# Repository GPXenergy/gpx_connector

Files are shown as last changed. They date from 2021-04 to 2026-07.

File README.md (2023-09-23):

# GPX Connector

The GPX-Connector is part of the GPX system to connect a smart meter to the GPX 
multi-user system. It runs on an ESP32, which connects to the smart meter 
through a RJ11 cable and sends the data over wifi to the GPX API. 

## Latest firmware

Check out the firmware directory for the latest firmware, separated by hardware 
version. You will find the firmware for your specific hardware in its own directory:

* gpx_connector_v1 (current prototype)
  * Latest firmware: gpx_connector_1.0.9.bin
* ...

## Local development setup

The project runs on [PlatformIO](https://platformio.org/), an open source 
framework and IDE for embedded development. 

This project has 2 platformio environments:
* __GPXConnector__ (default) - The final device / prototypes to run the system
* __wrover__ - The ESP-WROVER-kit device, used for debugging

Some platformio commands:
* `pio run`
  * Compile the program on default environment (GPXConnector)
* `pio run -t upload -e GPXConnector`
  * Compile and upload the program for specific environment
* `pio test -e wrover`
  * Run all the unit tests on the wrover environment

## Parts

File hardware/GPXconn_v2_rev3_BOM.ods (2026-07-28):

Reference | Qty | DNP | Mfr. No | alternative | Manufacturer | Value | Tolerance | Voltage rating | Dielectric | Footprint | Datasheet
C1 | 1 |  | DGH504Q5R5 |  | Cornell Dubilier | 0.5F | 30%/-10% | 5.5V |  | custom:CP_Radial_L17_W8.5_P12 | https://www.cde.com/resources/catalogs/DGH.pdf
C2,C3 | 2 |  | capacitor 0805 |  |  | 22µ | 20% | 10V | X5R | Capacitor_SMD:C_0805_2012Metric | ~
C4 | 1 |  | capacitor 0603 |  |  | 33p | 10% | 10V | C0G(NP0) | Capacitor_SMD:C_0603_1608Metric | ~
C5,C7,C11 | 3 |  | capacitor 0603 |  |  | 100n | 10% | 10V | X5R | Capacitor_SMD:C_0603_1608Metric | ~
C6,C9 | 2 |  | capacitor 0603 |  |  | 10µ | 20% | 10V | X5R | Capacitor_SMD:C_0603_1608Metric | ~
C8 | 1 |  | capacitor 0603 |  |  | 1µ | 20% | 10V | X5R | Capacitor_SMD:C_0603_1608Metric | ~
C10,J0 | 2 | DNP | DNP |  |  | DNP |  |  |  | Capacitor_SMD:C_0603_1608Metric,Resistor_SMD:R_0603_1608Metric | ~
CONN1 | 1 |  | MTJ-665X1 |  | Adam Tech | RJ11 |  |  |  | custom:AMPHENOL_54601-906WPLF
CONN2 | 1 |  | SJ2-35813B-SMT-TR |  | Same Sky | JACK-3.5MM-3P-SW |  |  |  | custom:CUI_SJ2-35813B-SMT-TR | ~
CONN3 | 1 | DNP | DNP |  |  | PINHD_R_1X62.54MM |  |  |  | Connector_PinHeader_2.54mm:PinHeader_1x06_P2.54mm_Vertical | ~
D1 | 1 |  | BAT60JFILM |  | STMicroelectronics |  |  |  |  | Diode_SMD:D_SOD-323 | https://www.st.com/resource/en/datasheet/bat60.pdf
D3 | 1 |  | NSR0340HT1G |  | onsemi |  |  |  |  | Diode_SMD:D_SOD-323 | https://www.onsemi.com/download/data-sheet/pdf/nsr0340h-d.pdf
F1 | 1 |  | 0686F0500-01 |  | Bel Fuse | Fuse 0603 |  |  |  | Fuse:Fuse_0603_1608Metric | ~
L1 | 1 |  | CVH252009-2R2M |  | Bourns | 2.2µH | 20% |  |  | Inductor_SMD:L_1008_2520Metric | ~
LED1 | 1 |  | 150505M173300 |  | Wurth Elektronik | LED-RGB-NOCMN |  |  |  | custom:LED_5050_3535_combined | https://downloads.cree-led.com/files/ds/h/HB-CLX6F-FKC.pdf
N2 | 1 |  | 51513530625F |  | Dialight | Light pipe |  |  |  | custom:lightpipe_panelmount | ~
Q1 | 1 |  | MMBT3904VL |  | Nexperia | BJT-NPN-SOT23 |  |  |  | custom:SOT23 | https://www.onsemi.com/pdf/datasheet/pzt3904-d.pdf
Q2 | 1 |  | DMP3099L-7 |  | Diodes Incorporated | MOSFET-PSOT23 |  |  |  | custom:SOT23 | https://www.diodes.com/assets/Datasheets/DMP3099L.pdf
Q3 | 1 |  | T2N7002AK |  | Toshiba | 2N7002H |  |  |  | custom:SOT23 | https://toshiba.semicon-storage.com/info/docget.jsp?did=29712&prodName=T2N7002AK
FB1,R17 | 2 |  | resistor 0603 |  |  | 0R |  |  |  | Resistor_SMD:R_0603_1608Metric | ~
R1 | 1 |  | resistor 0603 |  |  | 1k2 1% | 1% |  |  | Resistor_SMD:R_0603_1608Metric | ~
R2 | 1 |  | resistor 0603 |  |  | 51k 1% | 1% |  |  | Resistor_SMD:R_0603_1608Metric | ~
R3,R18,R19,R22,R27 | 5 |  | resistor 0603 |  |  | 10k | 1% |  |  | Resistor_SMD:R_0603_1608Metric | ~
R4 | 1 |  | resistor 0603 |  |  | 15k | 1% |  |  | Resistor_SMD:R_0603_1608Metric | ~
R5 | 1 |  | resistor 0603 |  |  | 47k | 1% |  |  | Resistor_SMD:R_0603_1608Metric | ~
R6,R20,R24,R25 | 4 |  | resistor 0603 |  |  | 5k1 | 1% |  |  | Resistor_SMD:R_0603_1608Metric | ~
R7 | 1 |  | resistor 0603 |  |  | 51 | 1% |  |  | Resistor_SMD:R_0603_1608Metric | ~
R8 | 1 |  | resistor 0603 |  |  | 115k 1% | 1% |  |  | Resistor_SMD:R_0603_1608Metric | ~
R9 | 1 |  | resistor 0603 |  |  | 25.5k 1% | 1% |  |  | Resistor_SMD:R_0603_1608Metric | ~
R10 | 1 |  | resistor 0603 |  |  | 47k 1% | 1% |  |  | Resistor_SMD:R_0603_1608Metric | ~
R11 | 1 |  | resistor 0603 |  |  | 18k 1% | 1% |  |  | Resistor_SMD:R_0603_1608Metric | ~
R12 | 1 |  | resistor 0603 |  |  | 750 | 1% |  |  | Resistor_SMD:R_0603_1608Metric | ~
R13 | 1 |  | resistor 0603 |  |  | 510 | 1% |  |  | Resistor_SMD:R_0603_1608Metric | ~
R14 | 1 |  | resistor 0603 |  |  | 1k6 | 1% |  |  | Resistor_SMD:R_0603_1608Metric | ~
R15,R16 | 2 |  | resistor 0603 |  |  | 100k | 1% |  |  | Resistor_SMD:R_0603_1608Metric | ~
R21,R23,R26 | 3 |  | resistor 0603 |  |  | 100 | 1% |  |  | Resistor_SMD:R_0603_1608Metric | ~
RS0 | 1 |  | RL0816S-R30-F |  | Susumu | 300mOhm 1% | 1% |  |  | Resistor_SMD:R_0603_1608Metric | ~
SW1 | 1 |  | 1MS1T2B4M6RE |  | MULTICOMP PRO | SW_SPDT |  |  |  | custom:SW-1MS1-T2-B4-M6 | http://www.farnell.com/datasheets/3968494.pdf
U1 | 1 |  | ESP32-WROOM-32E-H4 | ESP32-WROOM-32E-N16 | Espressif Systems | ESP-WROOM-3232D |  |  |  | RF_Module:ESP32-WROOM-32D | https://www.espressif.com/sites/default/files/documentation/esp32-wroom-32e_esp32-wroom-32ue_datasheet_en.pdf
U2 | 1 |  | TPS563252DRLR |  | Texas Instruments | TPS563252 |  |  |  | Package_TO_SOT_SMD:SOT-563 | https://www.ti.com/lit/ds/symlink/tps563252.pdf
U3 | 1 |  | NCS333ASQ3T2G |  | onsemi | OPAMP_5PIN-NCS333A |  |  |  | Package_TO_SOT_SMD:SOT-353_SC-70-5 | https://www.onsemi.com/download/data-sheet/pdf/ncs333-d.pdf
U4 | 1 |  | TLVH431BIL3T | TLV431BFTA | STMicroelectronics | VREFTL431 |  |  |  | custom:SOT23 | https://www.st.com/resource/en/datasheet/tlvh431.pdf
U5 | 1 |  | TESD5V0V4UCX6 RFG |  | Taiwan Semiconductor | TESD5V0V4UCX6 |  |  |  | custom:SOT457 | https://services.taiwansemi.com/storage/resources/datasheet/TESD5V0V4UCX6_B2003.pdf
USB1 | 1 |  | USB4105-GF-A |  | GCT | USB-C-2.0-16P |  |  |  | Connector_USB:USB_C_Receptacle_GCT_USB4105-xx-A_16P_TopMnt_Horizontal | https://www.usb.org/sites/default/files/documents/usb_type-c.zip

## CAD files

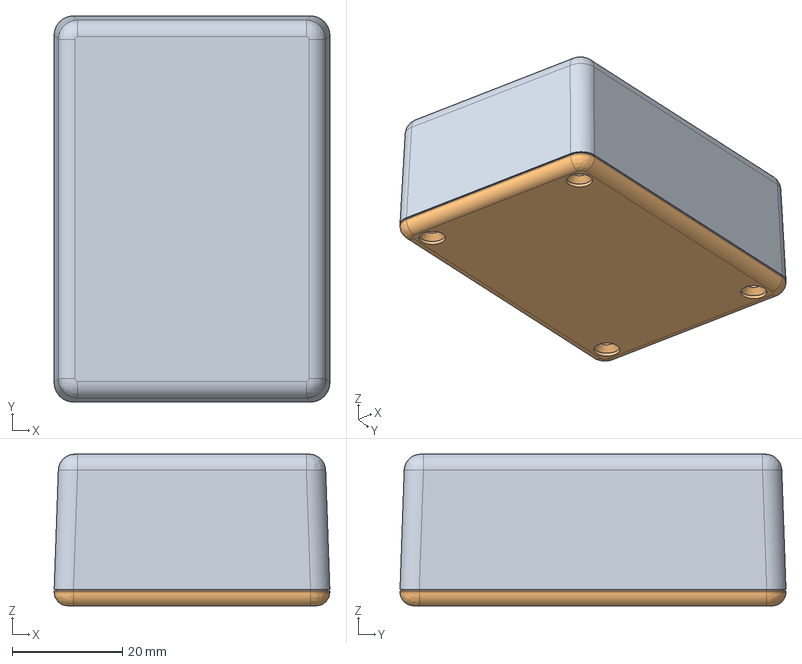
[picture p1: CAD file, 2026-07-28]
hardware/3Dmodels/TW5-3-7B.stp
50.0 x 70.0 x 27.5 mm
tw5-3-7(下ｶﾊﾞｰ)
tw5-3-7(上ｶﾊﾞｰ)

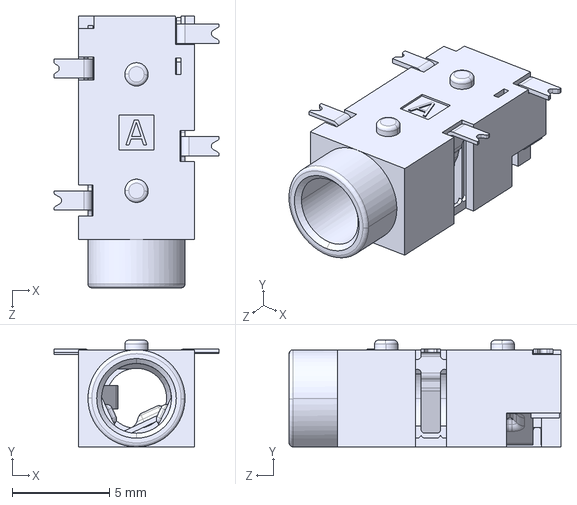
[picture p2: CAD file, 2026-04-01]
hardware/3Dmodels/Same_Sky_SJ2-35813B-SMT-TR.step
8.50 x 5.50 x 14.0 mm

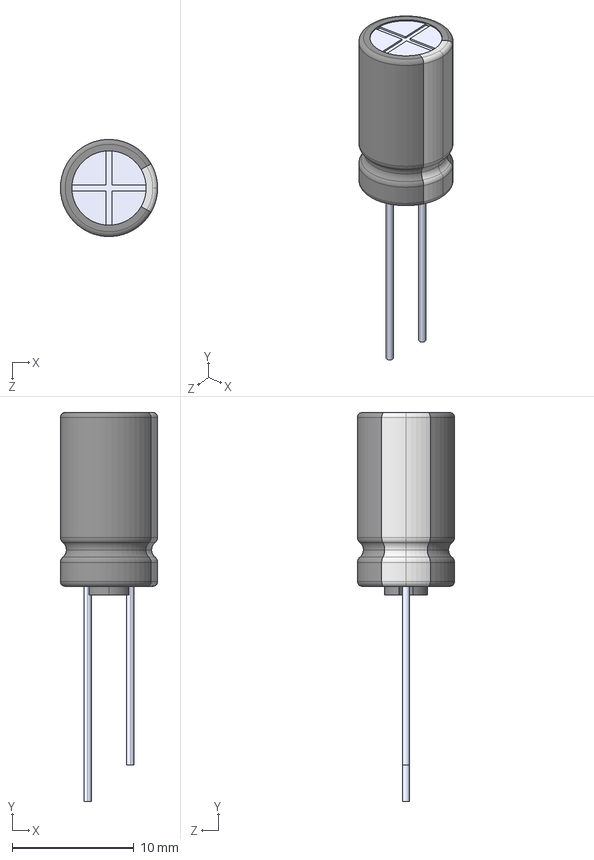
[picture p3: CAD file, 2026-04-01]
hardware/3Dmodels/EEU-FC1A681L.STEP
8.00 x 32.0 x 7.99 mm

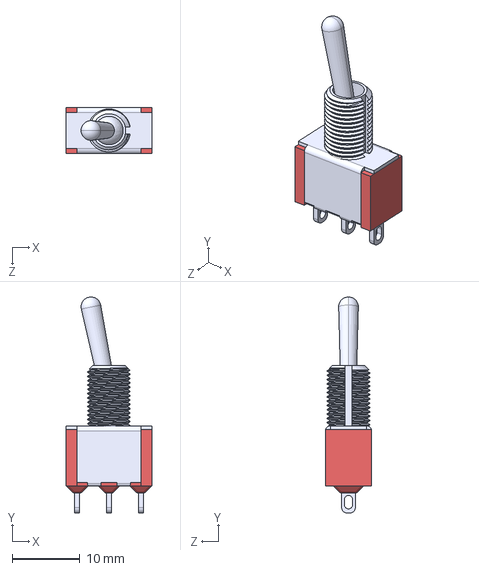
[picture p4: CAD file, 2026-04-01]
hardware/3Dmodels/100SP1T1B1M1QEH--3DModel-STEP-269445.STEP
12.7 x 31.9 x 6.86 mm

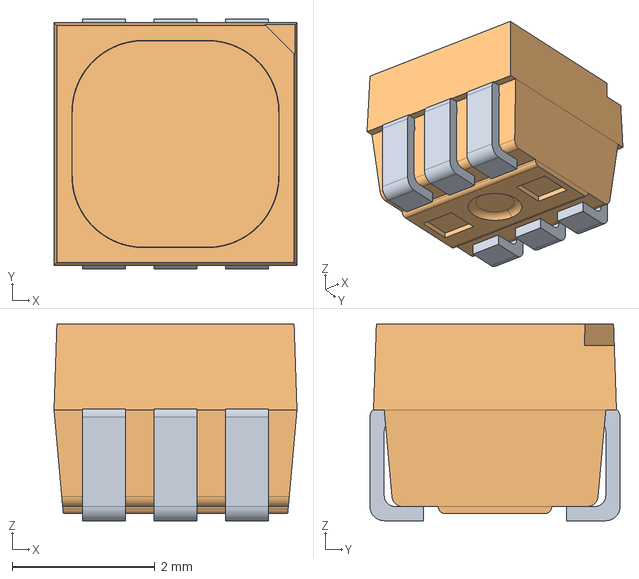
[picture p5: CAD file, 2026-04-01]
hardware/3Dmodels/LX6.stp
3.40 x 3.50 x 2.75 mm

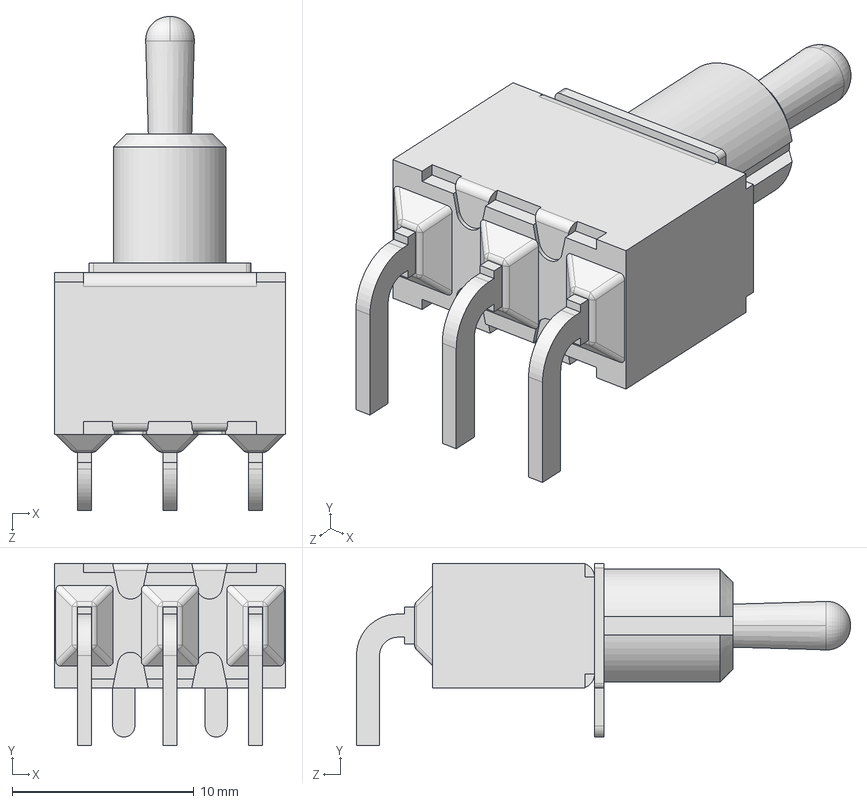
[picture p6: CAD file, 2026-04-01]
hardware/3Dmodels/100SP1T2B4M6QE--3DModel-STEP-613395.STEP
12.7 x 10.0 x 27.2 mm

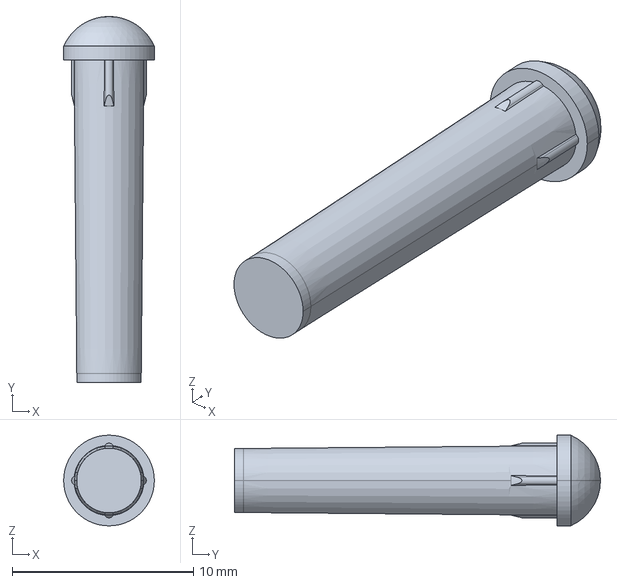
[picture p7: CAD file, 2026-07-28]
hardware/3Dmodels/51513530700f.stp
5.00 x 20.2 x 5.00 mm

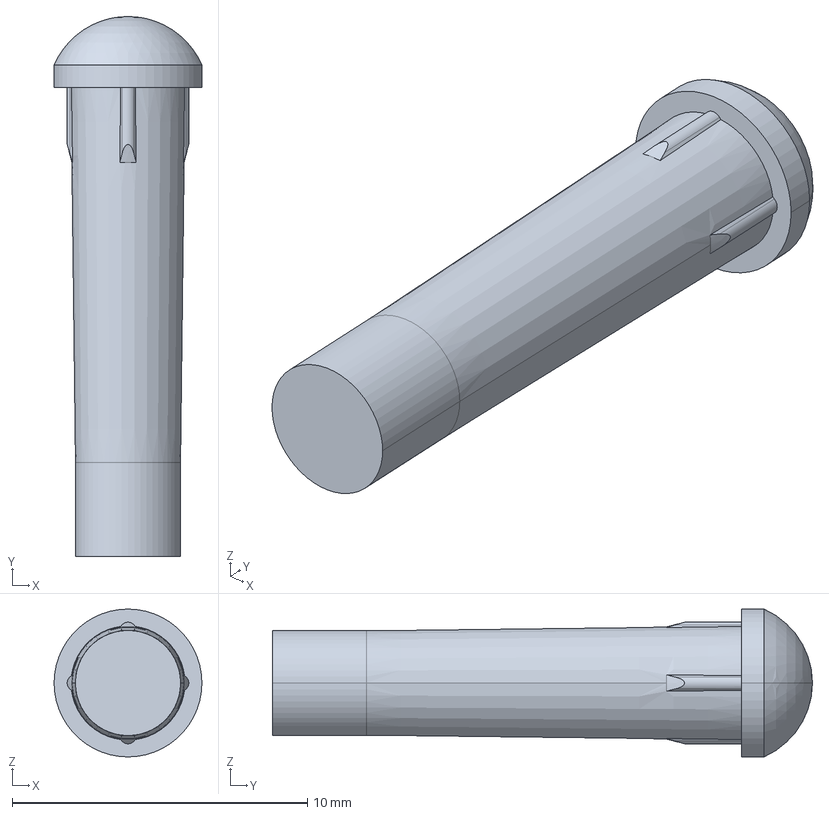
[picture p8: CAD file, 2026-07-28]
hardware/3Dmodels/51513530625F.stp
5.00 x 18.3 x 5.00 mm

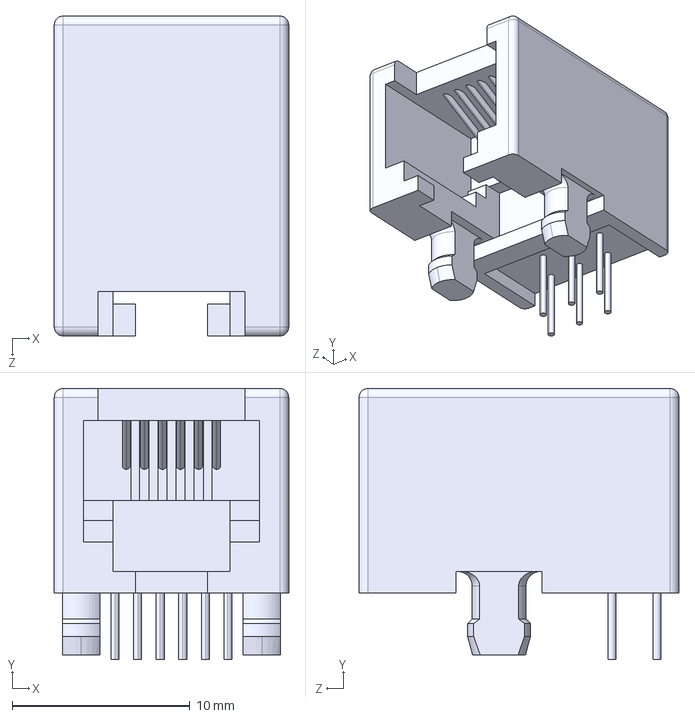
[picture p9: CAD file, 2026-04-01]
hardware/3Dmodels/54601-906WPLF.step
13.2 x 15.2 x 18.0 mm

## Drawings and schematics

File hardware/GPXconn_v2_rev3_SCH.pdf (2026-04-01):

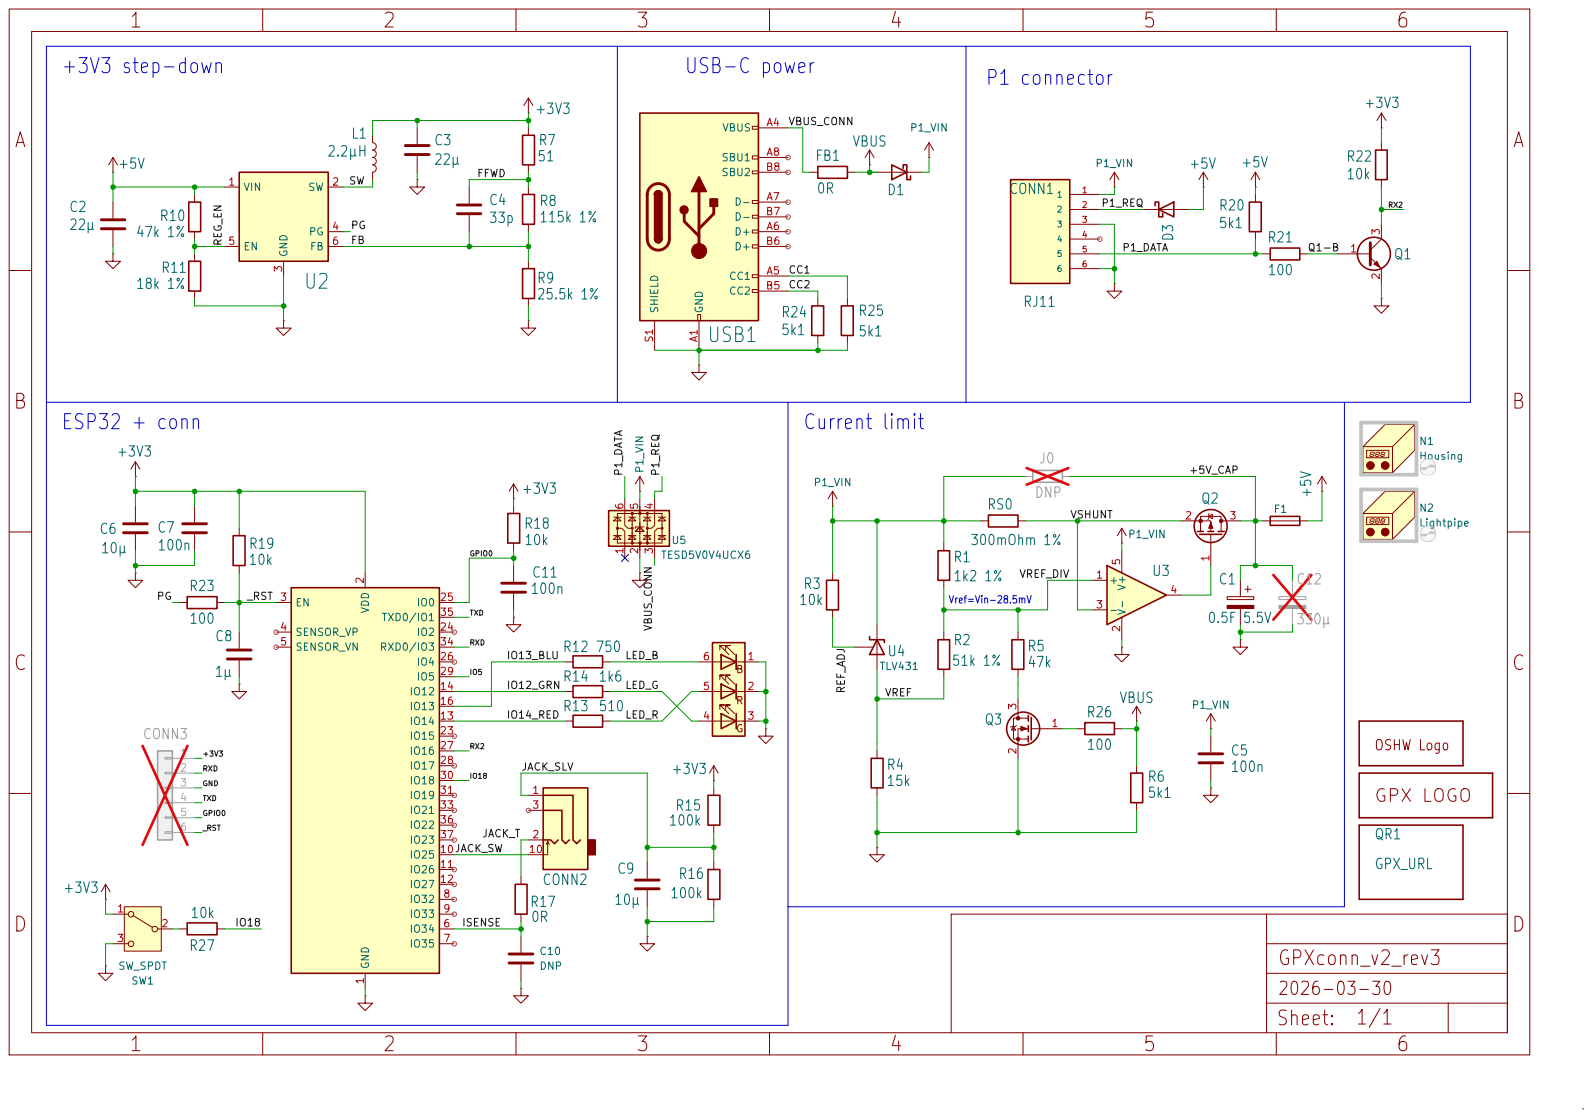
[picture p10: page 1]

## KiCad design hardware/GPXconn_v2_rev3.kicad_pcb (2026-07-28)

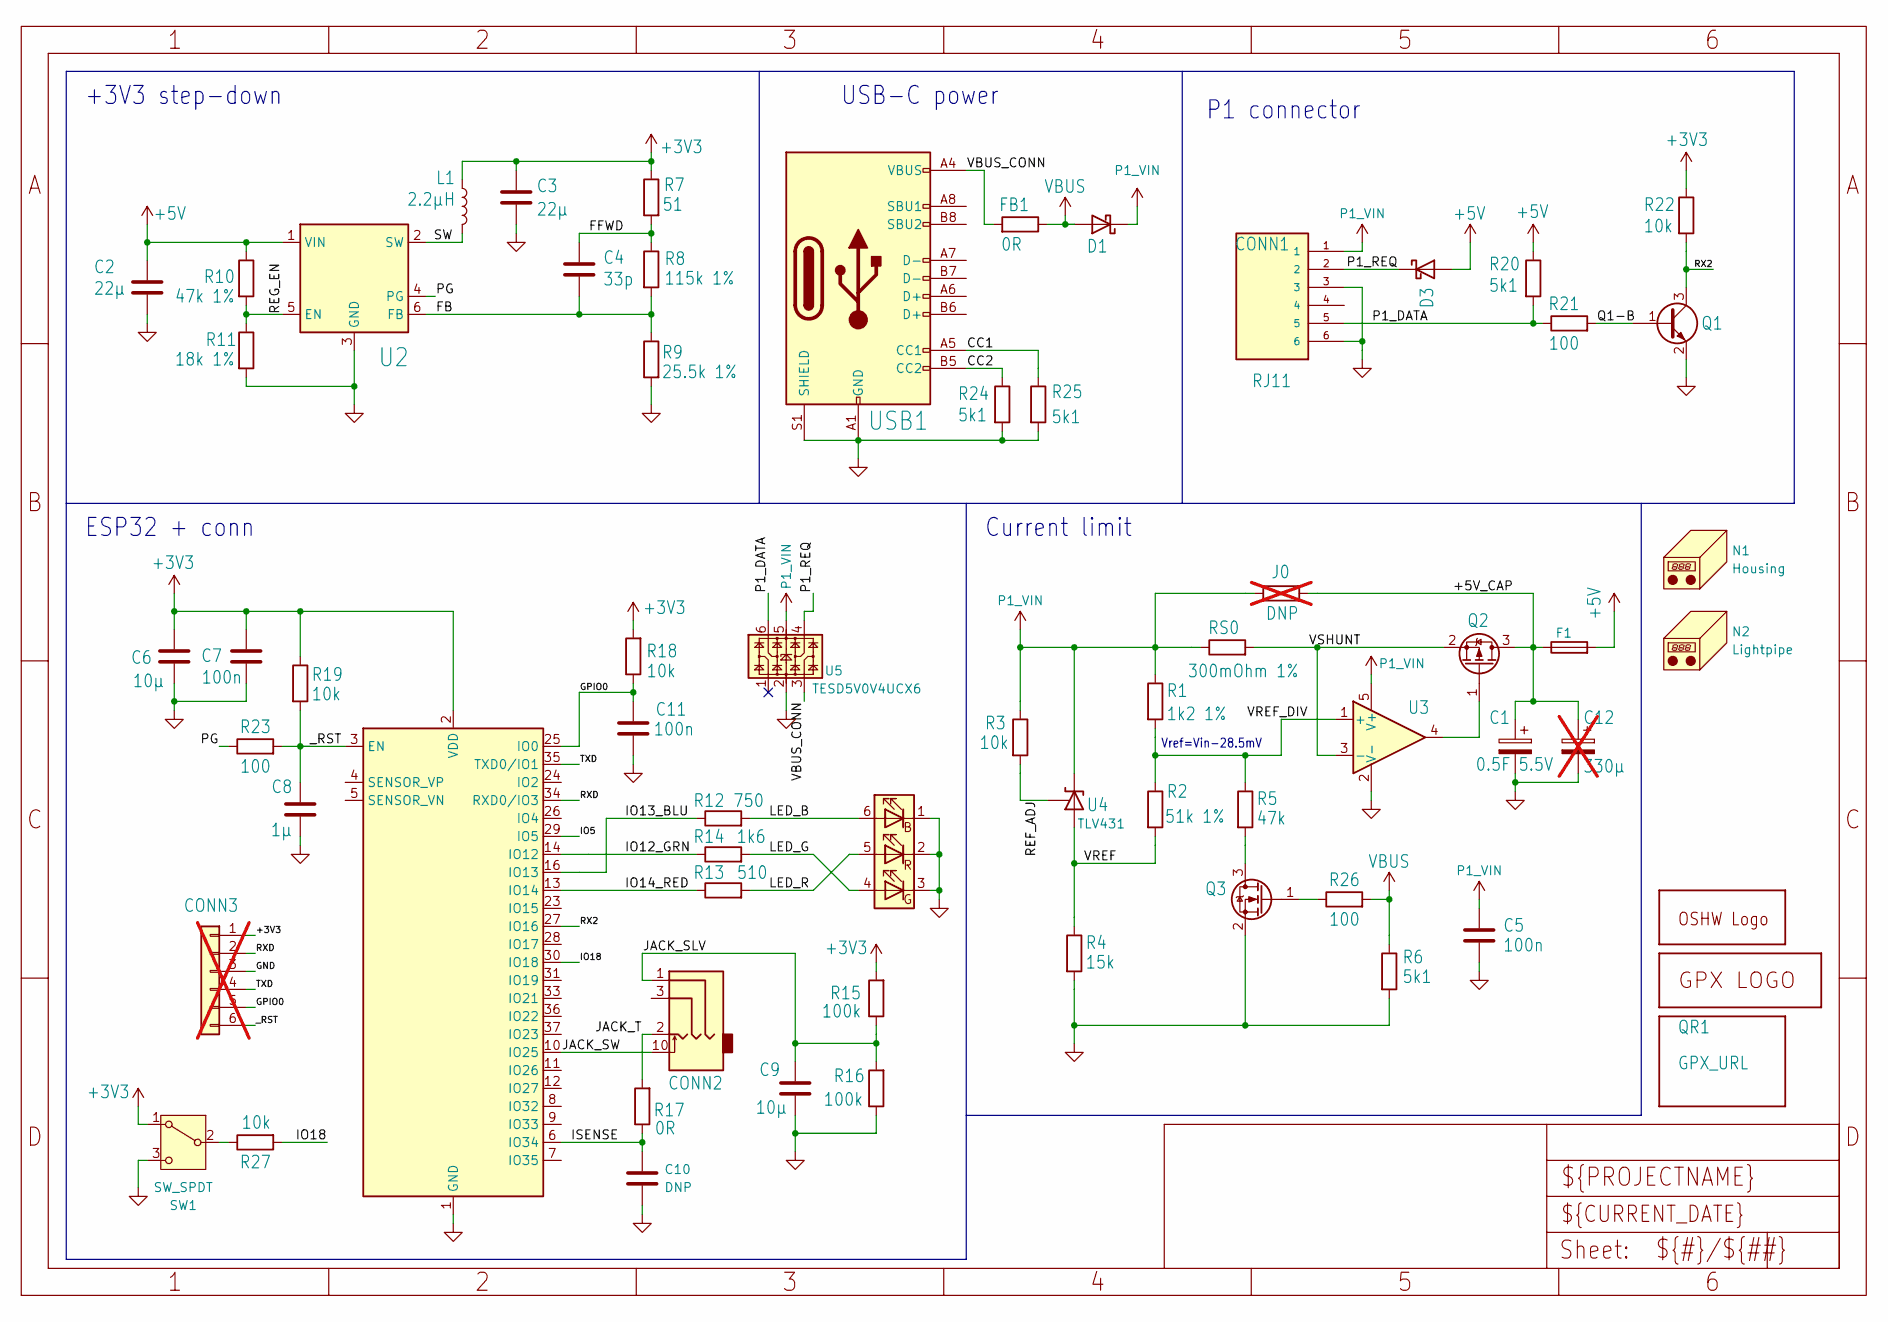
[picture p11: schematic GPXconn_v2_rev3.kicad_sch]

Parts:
C1: 0.5F 5.5V; CP_Radial_L17_W8.5_P12
C2, C3: 22µ; C_0805_2012Metric
C4: 33p; C_0603_1608Metric
C5, C7, C11: 100n; C_0603_1608Metric
C6, C9: 10µ; C_0603_1608Metric
C8: 1µ; C_0603_1608Metric
C10: DNP; C_0603_1608Metric
C12: 330µ; CP_Elec_6.3x7.7; not fitted
CONN1: RJ11; AMPHENOL_54601-906WPLF; PARTREV G
CONN2: JACK-3.5MM-3P-SW; CUI_SJ2-35813B-SMT-TR
CONN3: PINHD_R_1X62.54MM; PinHeader_1x06_P2.54mm_Vertical; not fitted
D1, D3: D-SCHOTTKY-SOD323-OL; D_SOD-323
F1: Fuse; Fuse_0603_1608Metric
FB1: 0R; R_0603_1608Metric
GOLD_ORB_SM1: OSHWLOGOLOGO8MM; OSHW-Symbol_6.7x6mm_SilkScreen
J0: DNP; R_0603_1608Metric; not fitted
L1: 2.2µH; L_1008_2520Metric
LED1: LED-RGB-NOCMN; LED_5050_3535_combined
N1: Housing; housing_TW5-3-7B
N2: Lightpipe; lightpipe_panelmount
Q1: MMBT3904; SOT23
Q2: DMP3099L-7; SOT23
Q3: 2N7002H; SOT23
QR1: GPX_URL; gpx_dash_qr_13x13
R1: 1k2 1%; R_0603_1608Metric
R2: 51k 1%; R_0603_1608Metric
R3, R18, R19, R22, R27: 10k; R_0603_1608Metric
R4: 15k; R_0603_1608Metric
R5: 47k; R_0603_1608Metric
R6, R20, R24, R25: 5k1; R_0603_1608Metric
R7: 51; R_0603_1608Metric
R8: 115k 1%; R_0603_1608Metric
R9: 25.5k 1%; R_0603_1608Metric
R10: 47k 1%; R_0603_1608Metric
R11: 18k 1%; R_0603_1608Metric
R12: 750; R_0603_1608Metric
R13: 510; R_0603_1608Metric
R14: 1k6; R_0603_1608Metric
R15, R16: 100k; R_0603_1608Metric
R17: 0R; R_0603_1608Metric
R21, R23, R26: 100; R_0603_1608Metric
RS0: 300mOhm 1%; R_0603_1608Metric
SW1: SW_SPDT; SW-1MS1-T2-B4-M6
U1: ESP-WROOM-3232D; ESP32-WROOM-32D
U2: TPS563252; SOT-563
U3: OPAMP_5PIN-NCS333A; SOT-353_SC-70-5
U4: TLV431; SOT23
U5: TESD5V0V4UCX6; SOT457
U$1: GPX_LOGO; gpx_logo
USB1: USB-C-2.0-16P; USB_C_Receptacle_GCT_USB4105-xx-A_16P_TopMnt_Horizontal

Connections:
+3V3: C3.2, C6.2, C7.2, CONN3.1, L1.2, R7.1, R15.2, R18.2, R19.1, R22.1, SW1.1 (A), U1.2 (VDD)
+5V: C2.2, D3.2 (A), F1.2, R10.1, R20.1, U2.1 (VIN)
/+5V_CAP: C1.1, C12.1, F1.1, J0.2, Q2.3 (D)
/CC1: R25.1, USB1.A5 (CC1)
/CC2: R24.1, USB1.B5 (CC2)
/FB: C4.2, R8.2, R9.1, U2.6 (FB)
/FFWD: C4.1, R7.2, R8.1
/GPIO0: C11.1, CONN3.5, R18.1, U1.25 (IO0)
/IO5: U1.29 (IO5)
/IO12_GRN: R14.1, U1.14 (IO12)
/IO13_BLU: R12.1, U1.16 (IO13)
/IO14_RED: R13.1, U1.13 (IO14)
/IO18: R27.2, U1.30 (IO18)
/ISENSE: C10.1, R17.1, U1.6 (IO34)
/JACK_SLV: C9.2, CONN2.1, R15.1, R16.2
/JACK_SW: CONN2.10, U1.10 (IO25)
/JACK_T: CONN2.2, R17.2
/LED_B: LED1.6 (BA), R12.2
/LED_G: LED1.4 (RA), R14.2
/LED_R: LED1.5 (GA), R13.2
/P1_DATA: CONN1.5, R20.2, R21.1, U5.6
/P1_REQ: CONN1.2, D3.1 (K), U5.4
/PG: R23.1, U2.4 (PG)
/Q1-B: Q1.1 (B), R21.2
/REF_ADJ: R3.2, U4.1 (REF)
/REG_EN: R10.2, R11.1, U2.5 (EN)
/RX2: Q1.3 (C), R22.2, U1.27 (IO16)
/RXD: CONN3.2, U1.34 (RXD0/IO3)
/SW: L1.1, U2.2 (SW)
/TXD: CONN3.4, U1.35 (TXD0/IO1)
/VBUS_CONN: FB1.2, U5.3, USB1.A4 (VBUS), USB1.A9 (VBUS), USB1.B4 (VBUS), USB1.B9 (VBUS)
/VREF: R2.2, R4.1, U4.3 (A)
/VREF_DIV: R1.2, R2.1, R5.1, U3.1 (+)
/VSHUNT: Q2.2 (S), RS0.2, U3.3 (-)
/_RST: C8.1, CONN3.6, R19.2, R23.2, U1.3 (EN)
GND: C1.2, C2.1, C3.1, C5.2, C6.1, C7.1, C8.2, C9.1, C10.2, C11.2, C12.2, CONN1.3, CONN1.6, CONN3.3, LED1.1 (BK), LED1.2 (GK), LED1.3 (RK), Q1.2 (E), Q3.2 (S), R4.2, R6.2, R9.2, R11.2, R16.1, R24.2, R25.2, SW1.3 (C), U1.1 (GND), U1.15 (GND), U1.38 (GND), U1.39 (GND), U2.3 (GND), U3.2 (V-), U5.2, USB1.A1 (GND), USB1.A12 (GND), USB1.B1 (GND), USB1.B12 (GND), USB1.S1 (SHIELD)
unnamed: Q2.1 (G), U3.4
unnamed: Q3.3 (D), R5.2
unnamed: Q3.1 (G), R26.1
unnamed: R27.1, SW1.2 (B)
P1_VIN: C5.1, CONN1.1, D1.1 (K), J0.1, R1.1, R3.1, RS0.1, U3.5 (V+), U4.2 (K), U5.5
VBUS: D1.2 (A), FB1.1, R6.1, R26.2

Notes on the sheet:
ESP32 + conn
USB-C power
Current limit
P1 connector
Vref=Vin-28.5mV
+3V3 step-down

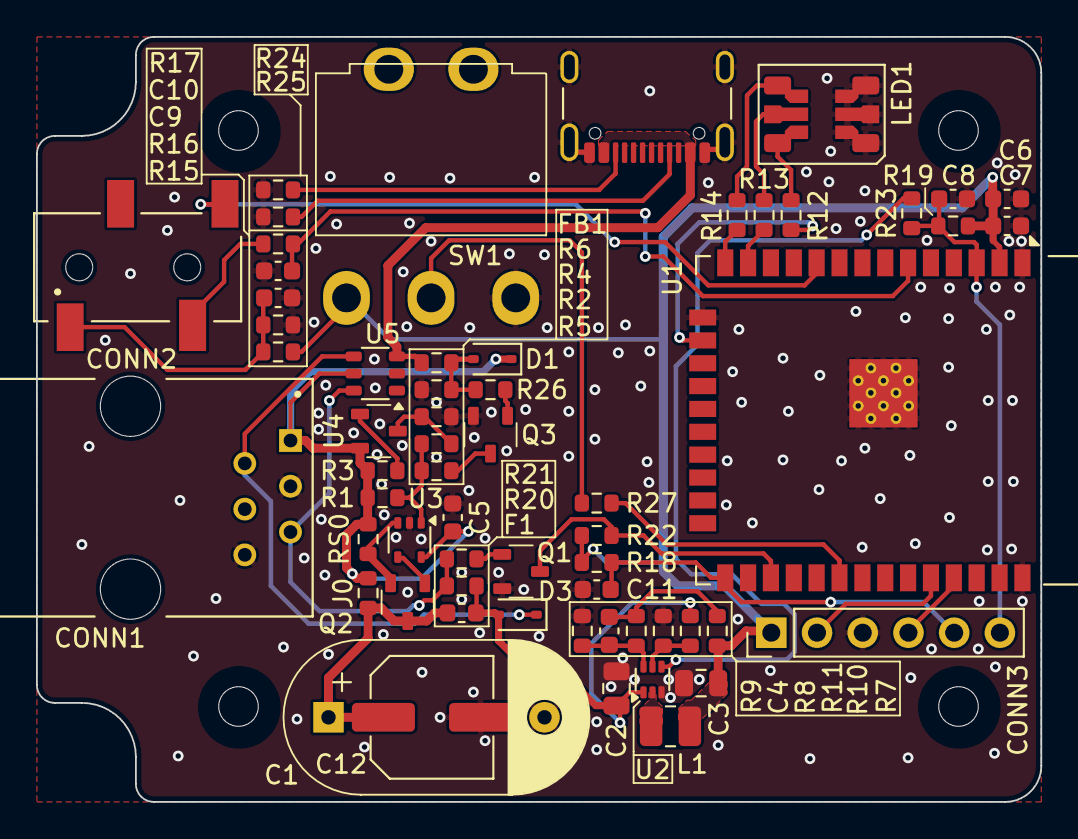
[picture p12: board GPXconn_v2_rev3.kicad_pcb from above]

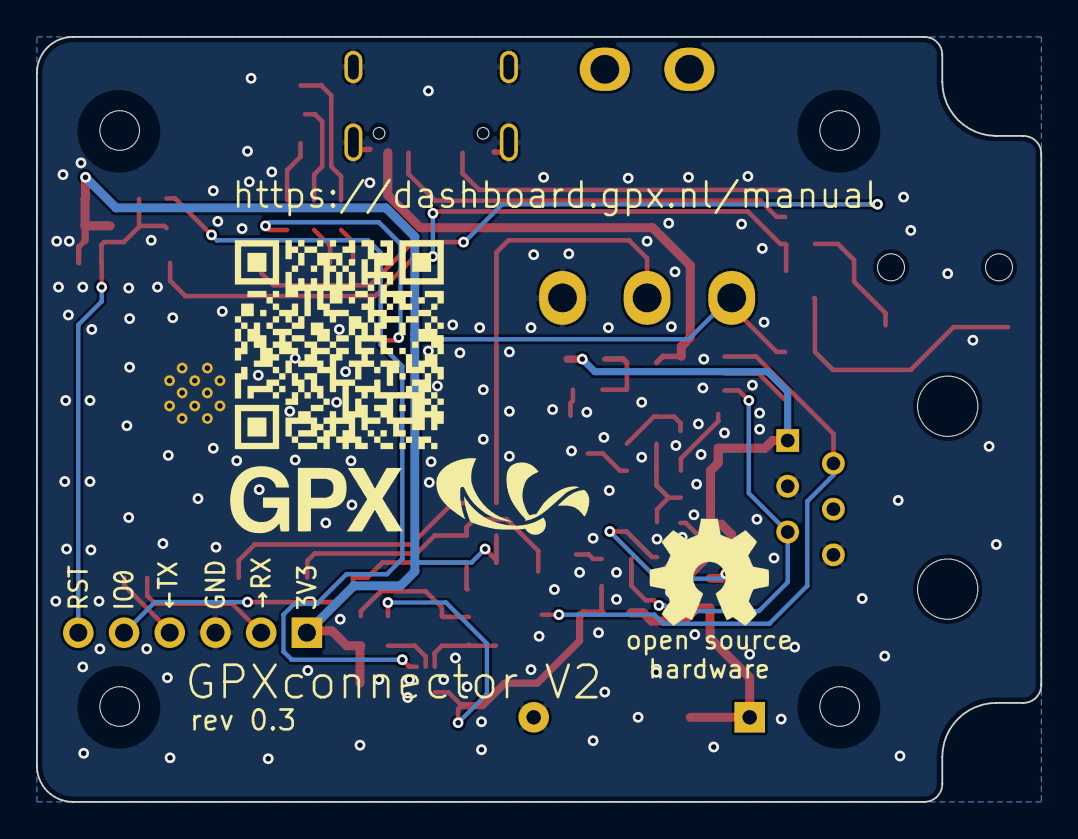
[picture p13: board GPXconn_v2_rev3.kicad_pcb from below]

Board: 2 copper layers, 55.8 x 42.5 mm, 65 parts (3 on the bottom side), 41 nets.

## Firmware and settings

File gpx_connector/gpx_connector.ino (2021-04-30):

#ifndef UNIT_TEST

#include <Arduino.h>
#include <Aggregator.hpp>

#include "api_connector.h"
#include "access_point.h"
#include "debugger.h"
#include "controller.h"
#include "smart_meter_connector.h"
#include "configuration_server.h"
#include "status_led.h"
#include "identifiers.h"
#include "mode_switch.h"
#include "inverter_connector.h"
#include "button.h"

HardwareSerial& SmartMeterSerialConnection = Serial2;

LocalStorage config;
Aggregator aggregator;

// Supervisors
StatusLed status_led;
Controller controller(config);

// Workers
Button reset_button(RESET_BUTTON_PIN);
SmartMeterConnector meter_connector(SmartMeterSerialConnection);
InverterConnector inverter_connector(config);
ConfigWebServer config_server(config, status_led);
AccessPoint access_point(config);
ModeSwitch mode_switch;

// Data handlers
ApiConnector api_reporter(config);


void status_led_loop(void* param) {
  for (;;) {
    status_led.loop();
    delay(50);
  }
}


void setup() {
  delay(2000);
  DEBUG_BEGIN(DEBUG_BAUD);

  /// Software configurations
  // init config
  config.initialize();

  /// Hardware configurations
  // Start serial connection to meter
  switch (config.get_meter_parity()) {
    case e_meter_parity_7E1:
      SmartMeterSerialConnection.begin(config.get_meter_baud(), SERIAL_7E1);
      break;
    case e_meter_parity_8N1:
      SmartMeterSerialConnection.begin(config.get_meter_baud(), SERIAL_8N1);
      break;
  }

  // Set gpio pin configurations
  gpio_config_t io_conf{
      .pin_bit_mask = 1ULL<<RESET_BUTTON_PIN,
      .mode = GPIO_MODE_INPUT,
      .pull_up_en = GPIO_PULLUP_ENABLE,
      .pull_down_en = GPIO_PULLDOWN_DISABLE,
      .intr_type = GPIO_INTR_DISABLE,
  };
  gpio_config(&io_conf);
  gpio_install_isr_service(ESP_INTR_FLAG_LEVEL1);

  SmartMeterSerialConnection.setRxBufferSize(4096);

  // Setup aggregator, which will initialize the workers/handlers/supervisors
  aggregator.register_worker(k_worker_reset_button, reset_button);
  aggregator.register_worker(k_worker_wifi_access_point, access_point);
  aggregator.register_worker(k_worker_meter_connector, meter_connector);
  aggregator.register_worker(k_worker_inverter_connector, inverter_connector);
  aggregator.register_worker(k_worker_wifi_config_server, config_server);
  aggregator.register_worker(k_worker_mode_switch, mode_switch);

  aggregator.register_handler(k_handler_api_reporter, api_reporter);

  aggregator.register_supervisor(status_led);
  aggregator.register_supervisor(controller);

  // Enable default workers and handlers
  aggregator.set_worker_active(k_worker_reset_button, true);
  aggregator.set_worker_active(k_worker_mode_switch, true);
  aggregator.set_worker_active(k_worker_wifi_config_server, true);

  xTaskCreate(status_led_loop, "led_loop", configMINIMAL_STACK_SIZE * 3, nullptr, 2, nullptr);

  DEBUG_PRINTLN("GPX-Connector initialized!");
}

void loop() {
  aggregator.run();
}


#endif

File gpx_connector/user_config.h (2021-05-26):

#ifndef USER_CONFIG_H
#define USER_CONFIG_H


enum MeterParity {
  e_meter_parity_7E1 = 0,
  e_meter_parity_8N1 = 1,
};


#ifndef GPX_CONN_VERSION
#define GPX_CONN_VERSION "1.0.dev"
#endif

/** Debug config **/
#define ENABLE_DEBUG 1
#define DEBUG_BAUD 115200

/** Hardware pins settings **/
#define RGB_LED_PIN_R 14
#define RGB_LED_PIN_G 12
#define RGB_LED_PIN_B 13
// Set this to true if we use anode LED
#define RGB_STATE_LED_REVERSED false

#define RESET_BUTTON_PIN 0

#define MODE_SWITCH_PIN 18

#define INVERTER_ADC_INPUT_PIN 34

/** API connector settings **/
#define API_HOST "dashboard.gpx.nl"
#define HEADER_API_CONTENT_TYPE "application/json"
#define HEADER_API_USER_AGENT "GPXCONN/" GPX_CONN_VERSION
#define API_MEASUREMENTS_ENDPOINT "https://" API_HOST "/api/meters/measurement/"
#define API_MEASUREMENTS_TEST_ENDPOINT API_MEASUREMENTS_ENDPOINT "test/"

/** Access point settings **/
#define SERVER_WIFI_PORT        80
#define ACCESS_POINT_IP         {192, 168, 5, 1}
#define ACCESS_POINT_NMASK      {255, 255, 255, 0}

/** Default ESP configurations **/
#define D_ACCESS_POINT_SSID     "GPXconnector"
#define D_ACCESS_POINT_PASSWORD "smartgpx"
#define D_WIFI_SSID             ""
#define D_WIFI_PASSWORD         ""
#define D_APIKEY                ""
#define D_METER_BAUD            115200
#define D_METER_PARITY          MeterParity::e_meter_parity_8N1
#define D_INVERTER_ENABLED      false
#define D_INVERTER_SENSOR_AMPS  30
#define D_INVERTER_PHASE_TYPE   1
#define D_APIKEY                ""
#define D_USE_DEV_SERVER        false

#endif

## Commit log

2021-01-18 initial commit transfer to github
    [configuration_server.h]
2021-04-07 add firmware copy script after release build, version number in platformio.ini, updated code with fixes
    [configuration_server.h]
2021-04-07 update status led colors, changed text for OTA update complete
2021-04-17 fix parity config for serial connection, update version
    [gpx_connector.ino, user_config.h]
2021-04-20 fix inverter connector watts calculation for different current sensors
    [inverter_connector.cpp]
2021-04-30 add reset config button
    [gpx_connector.ino, inverter_connector.cpp, user_config.h]
2021-05-01 add threshold for 30A/1V current sensors, add dev build filenames
2021-05-26 add separate option for 1 or 3 phase power, update config pages and local storage
2023-07-22 fix user api connector agent, added support for gas meter on separate bus
2023-09-23 v1.0.9 - fixes LED for success connection
2026-03-30 add hardware design files
    [100SP1T1B1M1QEH--3DModel-STEP-269445.STEP, 100SP1T2B4M6QE--3DModel-STEP-613395.STEP, 54601-906WPLF.step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]
